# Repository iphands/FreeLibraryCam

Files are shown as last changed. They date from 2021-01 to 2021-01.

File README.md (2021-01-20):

# Free Library Cam

## About
This project is for our [Little Free Library](https://littlefreelibrary.org/).
It adds a small camera to the library so that library patrons can snap a photo of themselves
and see it on the net.

## Note
This is still very much still a work in progress.

I'm working on the solar setup still (I lose power at around 1am :D),
and working on optimizing the power draw of the ESP32 still.

## It uses:
- An [ESP32-CAM module](https://www.amazon.com/gp/product/B07S5PVZKV/)
- An [over sized push button](https://www.amazon.com/gp/product/B071FSKY6Q/)
- Some spare solar parts I had laying around
- An old 12v to USB car adapter
- And a Python container server side

At the moment the setup uploads to [this Imgur album](https://imgur.com/a/nwV1Ow9).

## Pics
<table>
 <tr>
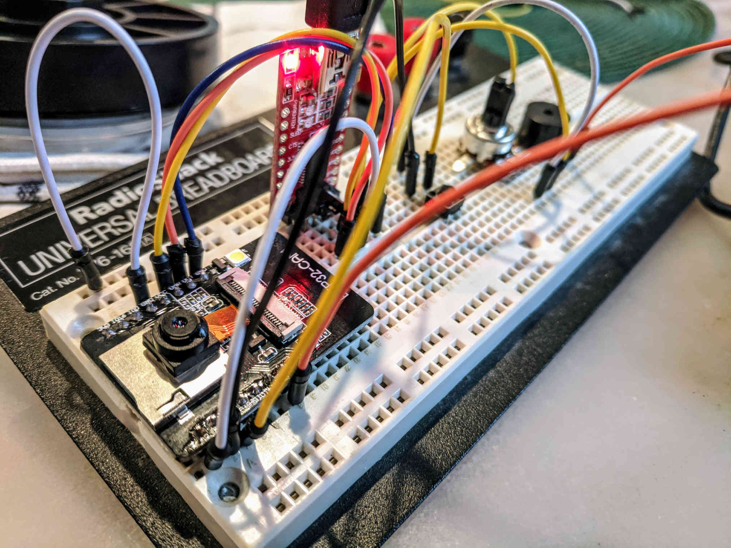
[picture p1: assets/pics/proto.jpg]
prototype board
  <td></td>
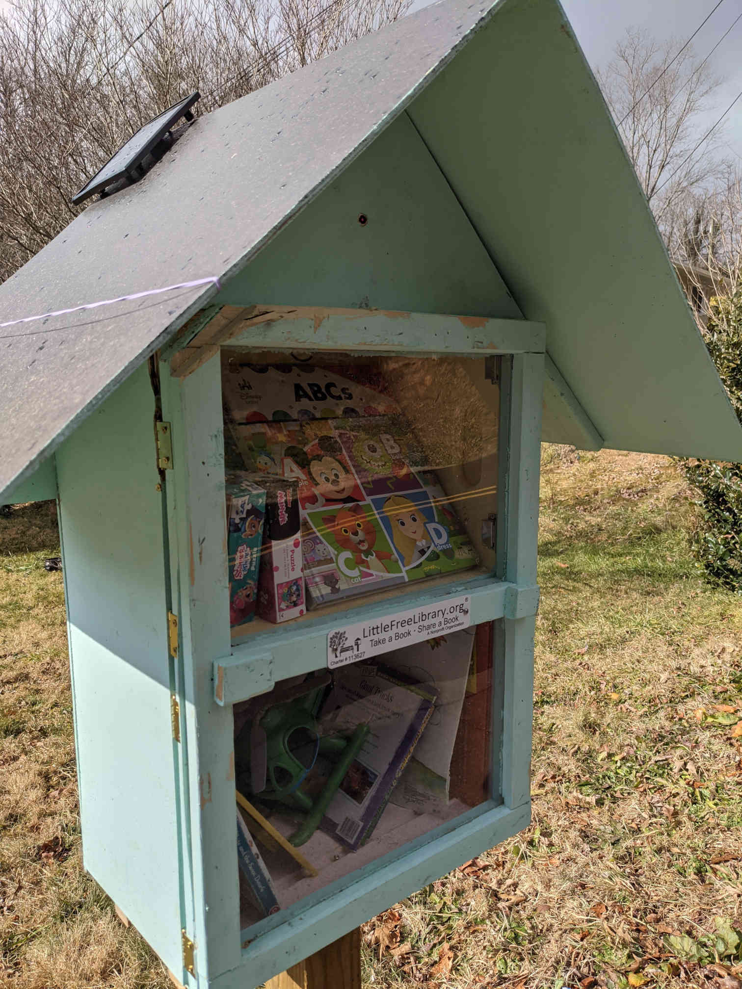
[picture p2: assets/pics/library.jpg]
library exterior
  <td></td>
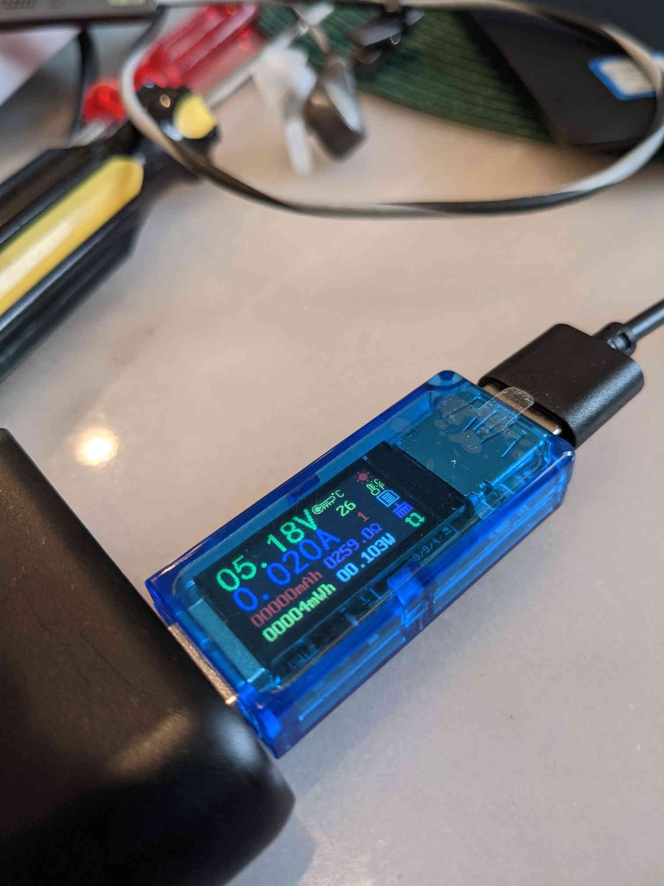
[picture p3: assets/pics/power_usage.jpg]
power usage
  <td></td>
 </tr>
 <tr>
  <td colspan="3">
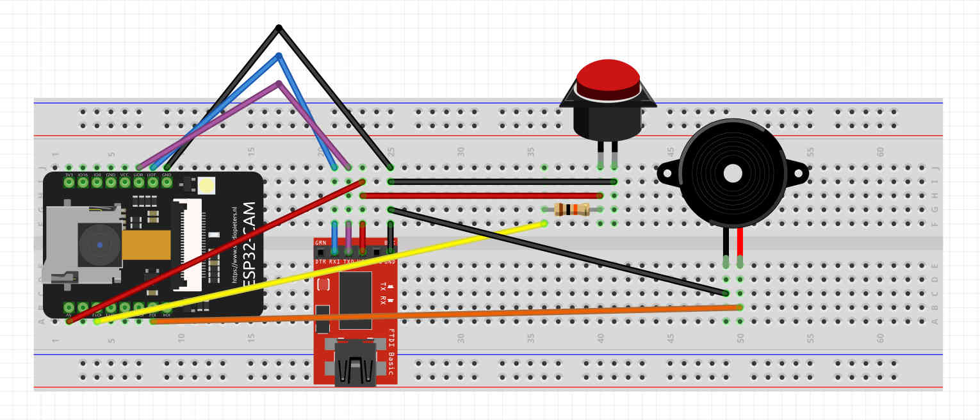
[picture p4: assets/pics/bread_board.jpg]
bread board
   </td>
  </td>
 </tr>
</table>

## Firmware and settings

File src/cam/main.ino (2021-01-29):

#include <Arduino.h>
#include <WiFi.h>
#include <TimeLib.h>
#include "soc/soc.h"
#include "soc/rtc_cntl_reg.h"
#include "esp_camera.h"
#include "secrets.h"
#include "esp32-hal-cpu.h"
#include "esp_wifi.h"
#include "esp_wifi_internal.h"
#include "nvs_flash.h"

#define uS_TO_S_FACTOR 1000000ULL

// const int LED = 4;
const int BUTTON      = 12;
const int SPEAKER     = 2;
const int LEDC_CHAN   = 15;
const int HTTP_BUFF   = 1460;
const int CHIRP_DELAY = 32;
const int SLEEP_SECS  = 300;

const String server_name = "camupload.lan";
const char* server_name_c = server_name.c_str();
const int server_port = 8000;

WiFiClient client;

// CAMERA_MODEL_AI_THINKER
#define PWDN_GPIO_NUM     32
#define RESET_GPIO_NUM    -1
#define XCLK_GPIO_NUM      0
#define SIOD_GPIO_NUM     26
#define SIOC_GPIO_NUM     27
#define Y9_GPIO_NUM       35
#define Y8_GPIO_NUM       34
#define Y7_GPIO_NUM       39
#define Y6_GPIO_NUM       36
#define Y5_GPIO_NUM       21
#define Y4_GPIO_NUM       19
#define Y3_GPIO_NUM       18
#define Y2_GPIO_NUM        5
#define VSYNC_GPIO_NUM    25
#define HREF_GPIO_NUM     23
#define PCLK_GPIO_NUM     22

// GLOBALS
int state = 0;
int sleep_count = 0;

void my_restart() {
  Serial.printf("\nin my_restart\n");

  pinMode(PWDN_GPIO_NUM, OUTPUT);

  // fugg with the camera to try and reset it
  for (int i = 0; i < 10; i += 1) {
    Serial.printf("power cycling cam?\n");
    digitalWrite(PWDN_GPIO_NUM, HIGH); delay(250);
    digitalWrite(PWDN_GPIO_NUM, LOW);  delay(250);
  }

  // Dont call this ESP.restart();
  // /**
  // * @brief  Restart PRO and APP CPUs.
  // *
  // * This function can be called both from PRO and APP CPUs.
  // * After successful restart, CPU reset reason will be SW_CPU_RESET.
  // * Peripherals (except for WiFi, BT, UART0, SPI1, and legacy timers) are not reset.
  // * This function does not return.
  // */
  // void esp_restart(void) __attribute__ ((noreturn));
  //
  // Peripherals (except for WiFi, BT, UART0, SPI1, and legacy timers) are not reset.
  // I need the cam to be reset!
  // Instead call deep sleep (I hope that powers down the cam for some time)

  Serial.printf("prepping for \"power cycle\"\n");
  esp_sleep_enable_timer_wakeup(15 * uS_TO_S_FACTOR);
  esp_deep_sleep_start();
}

void beep(uint freq, uint d) {
  ledcWriteTone(LEDC_CHAN, freq);
  delay(d);
  ledcWrite(LEDC_CHAN, 0);
}

void beep_sweep() {
  for (int i = 100; i < 3000; i += 100) {
    beep(i, 32);
  }
}

void beep_one_two_three_go() {
  beep(523,  512);
  delay(128);
  beep(523,  512);
  delay(128);
  beep(523,  512);
  delay(128);
  beep(1046, 750);
}

void beep_success() {
  beep(523, 128);
  delay(16);

  beep(659, 128);
  delay(16);

  beep(784, 256);
  ledcWrite(LEDC_CHAN, 0);
}

void beep_chirp() {
  beep(1500, CHIRP_DELAY);
  delay(CHIRP_DELAY);

  beep(1000, CHIRP_DELAY);
  delay(CHIRP_DELAY);

  beep(1500, CHIRP_DELAY);
}

void beep_error() {
  beep(300/2, 256);
  delay(10);
  beep(150/2, 256);
}

void do_wifi(bool output) {
  esp_wifi_start();
  esp_wifi_set_protocol(ESP_IF_WIFI_STA, WIFI_PROTOCOL_11B);
  esp_wifi_internal_set_fix_rate(ESP_IF_WIFI_STA, true, WIFI_PHY_RATE_1M_L);

  if (WiFi.status() != WL_CONNECTED) {
    if (output) {
      Serial.print("Connecting to ");
      Serial.println(ssid);
    }

    WiFi.begin(ssid, password);
    delay(500);

    int i = 0;
    while (WiFi.status() != WL_CONNECTED) {
      beep_chirp();
      Serial.print(".");
      delay(500);
      if (i > 25) { my_restart(); }
      i += 1;
    }

    if (output) {
      Serial.print("\nESP32-CAM IP Address: ");
      Serial.println(WiFi.localIP());
    }
  }
}

void setup() {
  Serial.begin(9600);
  Serial.println("");

  // pinMode(SPEAKER, OUTPUT);
  // pinMode(BUTTON, INPUT);
  // ledcSetup(LEDC_CHAN, 2000, 8);
  // ledcAttachPin(SPEAKER, LEDC_CHAN);
  // while (true) {
  // Serial.println("beeping\n");
  // beep_success();
  // }

  if (esp_reset_reason() == ESP_RST_DEEPSLEEP) {
    // if we just got back from a deep sleep
    // go ahead and restart again
    // desperate attemp to bulletproof hw fail here

    // trying this to combat the:
    // assertion "end <= ENTRY_COUNT" in nvs::Page::copyItems(nvs::Page&)
    // issue

    Serial.println("Just reset from a deep sleep... calling restart");
    ESP.restart();
  }

  pinMode(SPEAKER, OUTPUT);
  pinMode(BUTTON, INPUT);

  ledcSetup(LEDC_CHAN, 2000, 8);
  ledcAttachPin(SPEAKER, LEDC_CHAN);

  beep_chirp();
  WRITE_PERI_REG(RTC_CNTL_BROWN_OUT_REG, 0);

  camera_config_t config;
  config.ledc_channel = LEDC_CHANNEL_0;
  config.ledc_timer = LEDC_TIMER_0;
  config.pin_d0 = Y2_GPIO_NUM;
  config.pin_d1 = Y3_GPIO_NUM;
  config.pin_d2 = Y4_GPIO_NUM;
  config.pin_d3 = Y5_GPIO_NUM;
  config.pin_d4 = Y6_GPIO_NUM;
  config.pin_d5 = Y7_GPIO_NUM;
  config.pin_d6 = Y8_GPIO_NUM;
  config.pin_d7 = Y9_GPIO_NUM;
  config.pin_xclk = XCLK_GPIO_NUM;
  config.pin_pclk = PCLK_GPIO_NUM;
  config.pin_vsync = VSYNC_GPIO_NUM;
  config.pin_href = HREF_GPIO_NUM;
  config.pin_sscb_sda = SIOD_GPIO_NUM;
  config.pin_sscb_scl = SIOC_GPIO_NUM;
  config.pin_pwdn = PWDN_GPIO_NUM;
  config.pin_reset = RESET_GPIO_NUM;
  // config.xclk_freq_hz = 10000000;
  config.xclk_freq_hz = 20000000;
  config.pixel_format = PIXFORMAT_JPEG;

  config.frame_size = FRAMESIZE_XGA;
  config.jpeg_quality = 20;
  config.fb_count = 1;

  // camera init
  esp_err_t err = esp_camera_init(&config);

  if (err != ESP_OK) {
    // fugg with the camera to try and reset it
    for (int i = 0; i < 10; i += 1) {
      Serial.printf("power cycling cam?\n");
      digitalWrite(PWDN_GPIO_NUM, HIGH); delay(250);
      digitalWrite(PWDN_GPIO_NUM, LOW);  delay(250);

      err = esp_camera_init(&config);
      if (err == ESP_OK) {
        break;
      }
    }

    if (err != ESP_OK) {
      Serial.printf("Camera init failed with error 0x%x", err);
      my_restart();
    }
  }

  // WiFi.mode(WIFI_STA);
  do_wifi(true);
  ping_server(true);

  // Serial.printf("freq: %d\n", getCpuFrequencyMhz());
  // setCpuFrequencyMhz(80);
  // Serial.printf("freq: %d\n", getCpuFrequencyMhz());

  beep_success();
  esp_sleep_enable_timer_wakeup(SLEEP_SECS * uS_TO_S_FACTOR);
  esp_sleep_enable_ext0_wakeup((gpio_num_t)BUTTON, 0);
}

void sleep() {
  // esp_bt_controller_disable();
  // esp_wifi_stop();

  // I am not really sure if these need to be set again and again
  // imperically it seems no... but I have issues after about 2hr
  // where the board becomes unresponsive
  // esp_sleep_enable_timer_wakeup(SLEEP_SECS * uS_TO_S_FACTOR);
  // esp_sleep_enable_ext0_wakeup((gpio_num_t)BUTTON, 0);

  esp_light_sleep_start();

  if (sleep_count > 10) {
    // for some reason I consistently lose my board after 2hr
    // its a hack but just for safety reboot every 50 mins or so
    my_restart();
  }

  sleep_count += 1;
}

bool get_connection() {
  client.stop();
  delay(100);
  Serial.print("Connecting to " + server_name + ": ");
  for (int i = 0; i < 10; i++) {
    delay(100);

    if (client.connect(server_name_c, server_port)) {
      beep_chirp();
      Serial.println(" success");
      return true;
    }

    Serial.print("-");
    delay(250);
    do_wifi(false);
  }

  Serial.println(" failed");
  return false;
}

void ping_server(bool boot) {
  Serial.println("pinging server: " + server_name);
  if (get_connection()) {
    if (boot) {
      client.println("GET /boot HTTP/1.1");
    } else {
      client.println("GET /ping HTTP/1.1");
    }

    client.println("");
    Serial.println("ping successful!");
  }
}

void loop() {
  state = digitalRead(BUTTON);
  if (!state) {
    Serial.println("button pressed");
    sendPhoto();
  } else {
    ping_server(false);
    delay(100);
    sleep();
  }
}

void sendPhoto() {
  if (get_connection()) {
    camera_fb_t * fb = NULL;
    beep_one_two_three_go();
    fb = esp_camera_fb_get();

    beep_chirp();

    if (!fb) {
      Serial.println("Camera capture failed");
      my_restart();
    }

    String tail = "\r\n#DEADBEEF#\r\n";

    uint32_t imageLen = fb->len;
    // uint32_t extraLen = head.length() + tail.length();
    uint32_t extraLen = tail.length();
    uint32_t totalLen = imageLen + extraLen;

    client.println("POST / HTTP/1.1");
    client.println("Host: " + server_name);

    client.print("Content-Disposition: form-data; name=\"imageFile\"; filename=\"");
    client.print(year());
    client.print(month());
    client.print(day());
    client.print(hour());
    client.print(minute());
    client.print(second());
    client.println(".jpg\"");

    client.println("Content-Length: " + String(totalLen));
    client.println("Content-Type: multipart/form-data; boundary=#DEADBEEF#");
    client.println("");

    uint8_t *fbBuf = fb->buf;
    size_t fbLen = fb->len;

    for (size_t n = 0; n < fbLen; n = n + HTTP_BUFF) {
      beep_chirp();
      if (n + HTTP_BUFF < fbLen) {
        client.write(fbBuf, HTTP_BUFF);
        fbBuf += HTTP_BUFF;
      } else if (fbLen % HTTP_BUFF > 0) {
        size_t remainder = fbLen % HTTP_BUFF;
        client.write(fbBuf, remainder);
      }
    }

    client.print(tail);

    delay(100);
    beep_sweep();
    esp_camera_fb_return(fb);
  } else {
    Serial.println("Connection to " + server_name +  " failed.");
    beep_error();
  }

  sleep();
}

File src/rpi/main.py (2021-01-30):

import time
import os
import requests

from signal import pause
from gpiozero import Button
from gpiozero.pins.rpigpio import RPiGPIOFactory
from gpiozero import TonalBuzzer
from gpiozero import Device
from gpiozero.tones import Tone

SUCCESS = [
    ("E5", 0.200, 0.01),
    ("E5", 0.200, 0.01),
    ("E5", 0.200, 0.01),

    ("E5", 0.500, 0.001),

    ("C5", 0.500, 0.001),
    ("D5", 0.500, 0.001),

    ("E5", 0.200, 0.08),
    ("D5", 0.150, 0.01),
    ("E5", 0.600, 0),
]

HOLD_STILL = [
    ("C5", 0.400, 0.200),
    ("C5", 0.400, 0.200),
    ("C5", 0.400, 0.200),
    ("G5", 0.800, 0),
]

ERROR = [
    ("D4", 0.400, 0.01),
    ("A3", 0.800, 0),
]

Device.pin_factory = RPiGPIOFactory()
buzzer = TonalBuzzer("GPIO17")
button = Button("GPIO4")

def play(song, speed=False):
    for (note, duration, rest) in song:
        if speed:
            duration = duration * speed
            rest = rest * speed

        buzzer.play(Tone(note))
        time.sleep(duration)
        buzzer.stop()
        time.sleep(rest)

def button_callback():
    print("Button was pushed!")
    play(HOLD_STILL)

    # TAKE PICTURE
    os.system('raspistill -o /tmp/image.jpg --nopreview --exposure sports --timeout 1')

    # UPLOAD PICTURE
    with open('/tmp/image.jpg', 'rb') as f:
        data = f.read()
        r = requests.post(url='http://camupload.lan:8000/upload',
                          data=data,
                          headers={'Content-Type': 'application/octet-stream'})
        if r.status_code == 201:
            play(SUCCESS, speed=0.8)
        else:
            play(ERROR)

if __name__ == '__main__':
    button.when_pressed = button_callback
    # play(HOLD_STILL)
    # play(SUCCESS, speed=0.8)
    # play(ERROR)
    pause()

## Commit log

2021-01-18 adding power consumption optimzations
2021-01-19 adding power usage pic
2021-01-20 add schematic and bread board pic
    [cam_sketch.fzz]
2021-01-20 update to 10k ohm resistor
    [cam_sketch.fzz]
2021-01-25 add a reboot after 100 wakes
    [main.ino]
